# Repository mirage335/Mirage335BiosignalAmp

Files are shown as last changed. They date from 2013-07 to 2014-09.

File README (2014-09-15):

Copyright (C) 2012 mirage335
See the end of the file for license conditions.
See license.txt for Mirage335BiosignalAmp license conditions.

mirage335-site.dyndns.org
mirage335.dyndns.org/wiki/Mirage335BiosignalAmp
wiki.hacdc.org/index.php/Category:BiosignalAmplifier

Intended to represent the best achievable biosignal amplifier with commercially available components and dry electrodes. Input referred thermal noise across a 50Hz bandwidth should be about one microvolt at worst. Common-mode rejection is subject to real world conditions, but should far exceed commercial units.

New research was undertaken to select the best amplifier chips. See http://mirage335.dyndns.org/forums/viewtopic.php?f=4&t=16&sid=d09e2b47990c60269356eae3b596c3e3 for details.

USA companies provide all parts in these schematics.

__Usage__
The Driven Right Leg may be connected to any reference point on the body. The connection need not be very solid; it is far less critical than the active electrodes. Despite the name, for EEG purposes, the right leg may introduce undesirable ECG signals from the heart. An armband or heavy necklace may be more convenient.

The active electrodes may be used with pin headers in firm contact with dry skin, or saline sponges. Active electrode PCBs should be thoroughly and carefully sealed with hot glue or other heavy sealant.

Host board may be connected to USB, for signal processing with the Biosignal Processor software (https://github.com/mirage335/BiosignalProcessor), or taken directly in analog format from the BNC connector.

__Setup__
Obtain all parts from MOUSER/DigiKey as specified in the HTML Bill-Of-Materials files. Obtain circuit boards from oshpark.

Assemble the boards by placing and soldering components as per the PCB and BOM files. Recommend reflow soldering with laser cut solder stencil, except for the front-end high-performance amplifier chips.

PCB pads are provided for connection to metal shields. Aluminum foil, metal tins, and even random insullated wire may be effective.

Both power supplies should be > +/-6V < +/-15V . Mouser part 919-RS-1212D may provide suitable power.

SATA data cables are used to carry analog signals and power in one shielded cable.

Host board analog signal and USB outputs may be safely connected to non-isolated equipment, subject to the lightning strike warning below.

Host board USB data acqusition system is derrived from ArduinoDAQ. Essentially an Arduino Leonardo clone, an ISP programmer or arduino is required to flash firmware.

__Safety__
TEST the "HV Suppressor" transistor circuits. They protect users from amplifier chips failing short-circuit to power supply rails.

The safety critical isolation line marked on the test board includes upstream components. These must not be exposed to >25uA ground referenced current. Batteries may be safe when properly connected. Wall-warts, ATX power supplies, and even electrical grounds, are extremely dangerous.

Nearby lightning strikes will penetrate the isolation amplifier. A low-impedance earth connection to -ONLY- the non-isolated Vgnd may divert these faults. Alternatively, some 3-prong surge protectors may help, but they must clamp fast and well below 1.5kV. 
High frequency radio transmissions will penetrate the isolation amplifier. Amateur radio operators should be careful.

Passive electrodes -must- include the HV suppressors found on the active electrode boards. The most convenient way to build passive electrodes is to replace the amplifier chip on the active electrode board with a wire between pins 3 and 6.

No claim of liability is made by anyone. Your accident is your accident. Use common sense. If you don't understand the safety features and limitations, don't use this circuit.

__Copyright__
This file is part of Mirage335BiosignalAmp.

Mirage335BiosignalAmp is free software: you can redistribute it and/or modify
it under the terms of the GNU General Public License as published by
the Free Software Foundation, either version 3 of the License, or
(at your option) any later version.

Mirage335BiosignalAmp is distributed in the hope that it will be useful,
but WITHOUT ANY WARRANTY; without even the implied warranty of
MERCHANTABILITY or FITNESS FOR A PARTICULAR PURPOSE.  See the
GNU General Public License for more details.

You should have received a copy of the GNU General Public License
along with Mirage335BiosignalAmp.  If not, see <http://www.gnu.org/licenses/>.

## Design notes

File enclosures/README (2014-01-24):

These enclosures are still under development, having been partially tested on older versions of the Mirage335BiosignalAmplifier hardware. They may require significant readjustment.

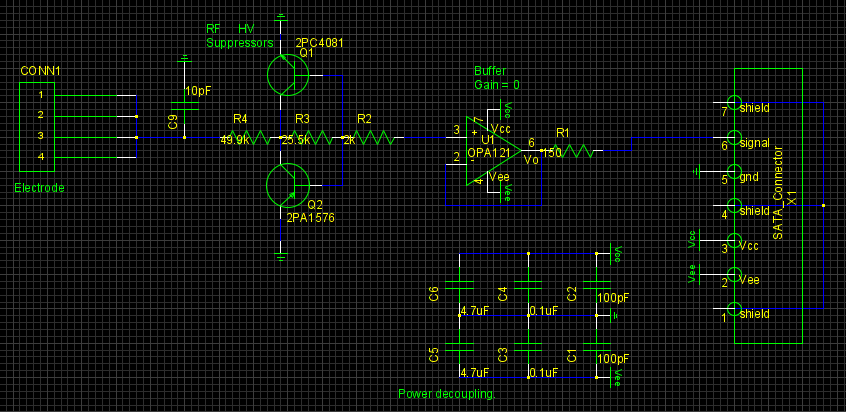
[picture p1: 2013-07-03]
activeElectrodeSchematic.png

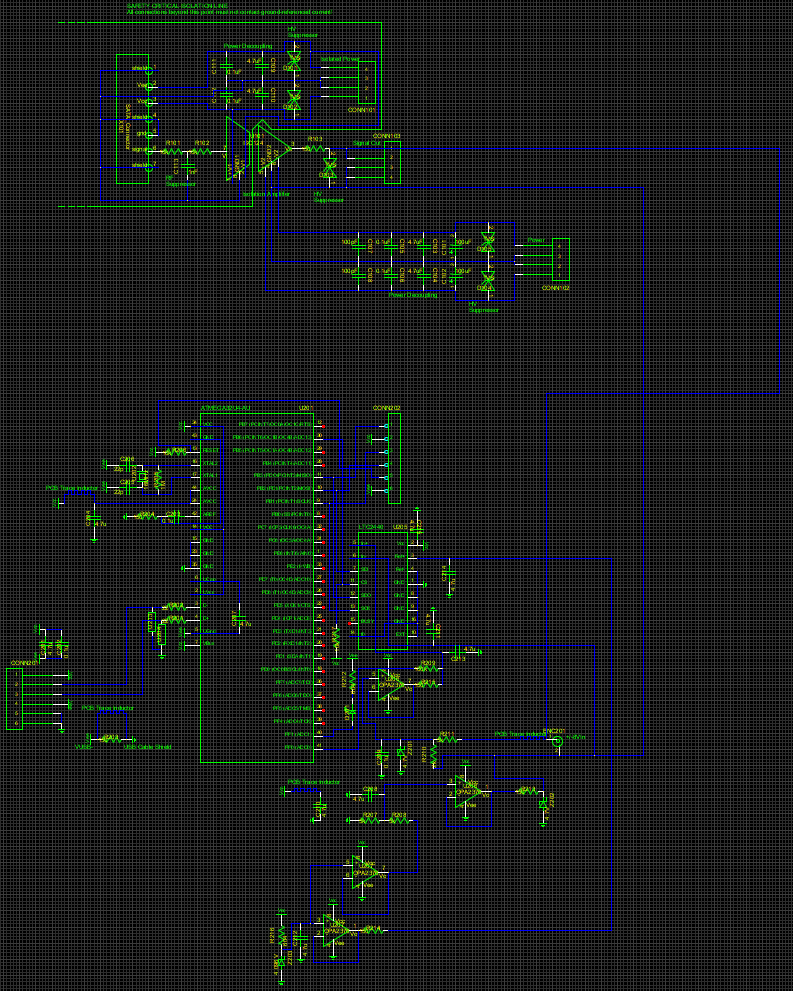
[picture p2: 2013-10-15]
hostSchematic.png

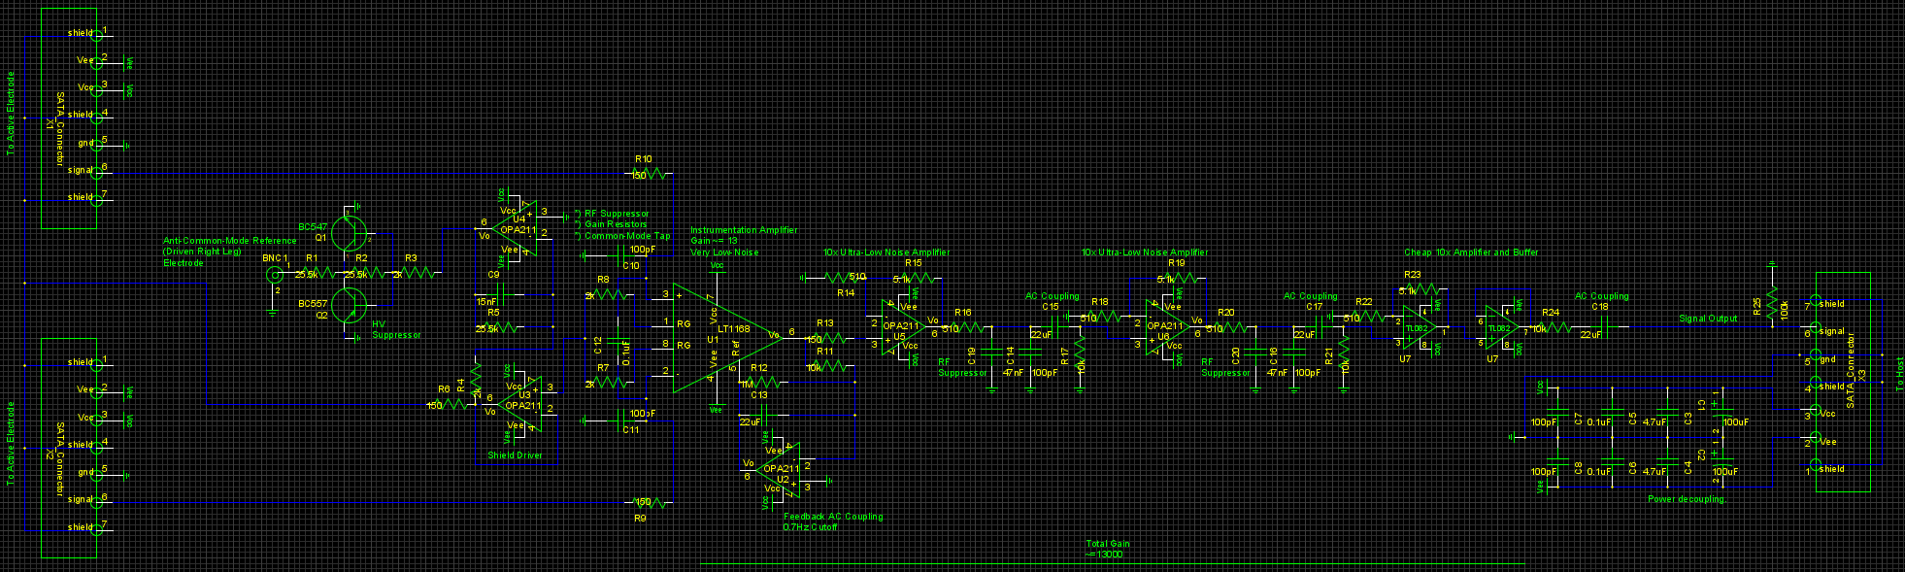
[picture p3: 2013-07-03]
amplifierSchematic.png

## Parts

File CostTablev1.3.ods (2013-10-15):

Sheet: Parts
ActiveElectrode
U1 | OPA121 | OPA121 | - | SO8 | $12.06 | 1 | $12.06 | 2 | $24.12
R4 | RESISTOR | RESISTOR | 49.9k | 1206 | $0.55 | 1 | $0.55 | 2 | $1.10
C5,C6 | CAPACITOR | CAPACITOR | 4.7uF | 1206 | $0.45 | 2 | $0.90 | 2 | $1.80
C3,C4 | CAPACITOR | CAPACITOR | 0.1uF | 1206 | $0.10 | 2 | $0.20 | 2 | $0.40
C1,C2 | CAPACITOR | CAPACITOR | 100pF | 805 | $1.04 | 2 | $2.08 | 2 | $4.16
R2 | RESISTOR | RESISTOR | 2k | 1206 | $0.55 | 1 | $0.55 | 2 | $1.10
R3 | RESISTOR | RESISTOR | 25.5k | 1206 | $0.55 | 1 | $0.55 | 2 | $1.10
C9 | CAPACITOR | CAPACITOR | 10pF | 805 | $0.62 | 1 | $0.62 | 2 | $1.24
R1 | RESISTOR | RESISTOR | 150 | 1206 | $0.55 | 1 | $0.55 | 2 | $1.10
X1 | SATA_Connector | SATA_Connector | - | 517-5607-4200-SH | $0.81 | 1 | $0.81 | 2 | $1.62
CONN1 | CONNECTOR_4 | OTHER | - | HEADER4_1 | $0.15 | 1 | $0.15 | 2 | $0.30
Q2 | 2PA1576 | OTHER | - | SC70_3 | $0.05 | 1 | $0.05 | 2 | $0.10
Q1 | 2PC4081 | OTHER | - | SC70_3 | $0.05 | 1 | $0.05 | 2 | $0.10
Amplifier |  | OTHER
U1 | LT1168 | LT1168 | - | SO8 | $7.66 | 1 | $7.66 | 1 | $7.66
R12 | RESISTOR | RESISTOR | 1M | 1206 | $0.09 | 1 | $0.09 | 1 | $0.09
R10,R13,R6,R9 | RESISTOR | RESISTOR | 150 | 1206 | $0.55 | 4 | $2.20 | 1 | $2.20
C9 | CAPACITOR | CAPACITOR | 15nF | 1206 | $0.27 | 1 | $0.27 | 1 | $0.27
U2,U3,U4,U5,U6 | OPA211 | OPA211 | - | SO8 | $7.76 | 5 | $38.80 | 1 | $38.80
U7 | TL082 | OTHER | - | SO8 | $0.45 | 1 | $0.45 | 1 | $0.45
C10,C11,C16 | CAPACITOR | CAPACITOR | 100pF | 805 | $1.04 | 3 | $3.12 | 1 | $3.12
C15,C17 | CAPACITOR | CAPACITOR | 22uF | 1210 | $1.71 | 2 | $3.42 | 1 | $3.42 | $3.42
R14,R16,R18,R20,R22 | RESISTOR | RESISTOR | 510 | 1206 | $0.09 | 5 | $0.45 | 1 | $0.45
R15,R19,R23 | RESISTOR | RESISTOR | 5.1k | 1206 | $0.10 | 3 | $0.30 | 1 | $0.30
R11,R17,R21,R24 | RESISTOR | RESISTOR | 10k | 1206 | $0.09 | 4 | $0.36 | 1 | $0.36
R3,R4,R7,R8 | RESISTOR | RESISTOR | 2k | 1206 | $0.55 | 4 | $2.20 | 1 | $2.20
C1,C2 | POLARIZED_CAPACITOR | POLARIZED_CAPACITOR | 100uF | EIA7343 | $2.96 | 2 | $5.92 | 1 | $5.92 | $5.92
C3,C4 | CAPACITOR | CAPACITOR | 4.7uF | 1206 | $0.45 | 2 | $0.90 | 1 | $0.90
C14,C7,C8 | CAPACITOR | CAPACITOR | 100pF | 805 | $1.04 | 3 | $3.12 | 1 | $3.12 | $3.12
R1,R2,R5 | RESISTOR | RESISTOR | 25.5k | 1206 | $0.55 | 3 | $1.65 | 1 | $1.65
Q1 | BC547 | OTHER | - | TO92 | $0.06 | 1 | $0.06 | 1 | $0.06
BNC1 | BNC | OTHER | - | BNC_LAY | $1.74 | 1 | $1.74 | 1 | $1.74
C12,C5,C6 | CAPACITOR | CAPACITOR | 0.1uF | 1206 | $0.10 | 3 | $0.30 | 1 | $0.30
X1,X2,X3 | SATA_Connector | SATA_Connector | - | 517-5607-4200-SH | $0.81 | 3 | $2.43 | 1 | $2.43
C19,C20 | CAPACITOR | CAPACITOR | 47nF | 1206 | $0.18 | 2 | $0.36 | 1 | $0.36
R25 | RESISTOR | RESISTOR | 100k | 805 | $0.16 | 1 | $0.16 | 1 | $0.16
C13,C18 | CAPACITOR | CAPACITOR | 22uF | 1210 | $1.71 | 2 | $3.42 | 1 | $3.42
Q2 | PNP_TRANSISTOR | OTHER | BC557 | TO92 | $0.07 | 1 | $0.07 | 1 | $0.07
Host |  | OTHER
X101 | SATA_Connector | SATA_Connector | - | 517-5607-4200-SH | $0.81 | 1 | $0.81 | 1 | $0.81
U101 | ISO124 | ISO124 | - | DIP16_highIsolation | $16.42 | 1 | $16.42 | 1 | $16.42
C101,C102 | POLARIZED_CAPACITOR | POLARIZED_CAPACITOR | 100uF | EIA7343 | $2.96 | 2 | $5.92 | 1 | $5.92
C107,C108 | CAPACITOR | CAPACITOR | 100pF | 805 | $1.04 | 2 | $2.08 | 1 | $2.08
C105,C106,C111,C112 | CAPACITOR | CAPACITOR | 0.1uF | 1206 | $0.10 | 4 | $0.40 | 1 | $0.40
C113 | CAPACITOR | CAPACITOR | 1nF | 1206 | $0.07 | 1 | $0.07 | 1 | $0.07
D101,D102,D103,D104,D105 | TVS | OTHER | - | DO214AB | $0.33 | 5 | $1.65 | 1 | $1.65
CONN101,CONN102,CONN103 | CONNECTOR_4 | OTHER | - | HEADER4_1 | $0.37 | 3 | $1.11 | 1 | $1.11
C103,C104,C109,C110 | CAPACITOR | CAPACITOR | 4.7uF | 1206 | $0.45 | 4 | $1.80 | 1 | $1.80
U201 | ATMEGA32U4-AU | ATMEGA32U4-AU | - | TQFP44_10 | $6.04 | 1 | $6.04 | 1 | $6.04
R205 | RESISTOR | RESISTOR | 1M | 1206 | $0.09 | 1 | $0.09 | 1 | $0.09
U202 | CRYSTAL | OTHER | 16MHz | ACY200 | $0.39 | 1 | $0.39 | 1 | $0.39
C205,C206 | CAPACITOR | CAPACITOR | 22p | 805 | $0.10 | 2 | $0.20 | 1 | $0.20
CONN202 | CONNECTOR_6 | OTHER | - | HEADER6_2 | $0.25 | 1 | $0.25 | 1 | $0.25
R201,R202 | RESISTOR | RESISTOR | 22 | 805 | $0.52 | 2 | $1.04 | 1 | $1.04
U203,U204 | ESD_Suppressor | OTHER | - | 603 | $0.13 | 2 | $0.26 | 1 | $0.26
CONN201 | CONNECTOR_6 | OTHER | - | USB_B | $0.58 | 1 | $0.58 | 1 | $0.58
R209 | RESISTOR | RESISTOR | 100k | 805 | $0.16 | 1 | $0.16 | 1 | $0.16
C202,C203,C209 | CAPACITOR | CAPACITOR | 0.1u | 1206 | $0.10 | 3 | $0.30 | 1 | $0.30
U205 | LTC2440 | LTC2440 | - | SSOP16 | $11.18 | 1 | $11.18 | 1 | $11.18
D201 | LED | OTHER | - | 402 | $0.09 | 1 | $0.09 | 1 | $0.09
R210 | RESISTOR | RESISTOR | 2k | 1206 | $0.55 | 1 | $0.55 | 1 | $0.55
R207,R208,R211 | RESISTOR | RESISTOR | 5k | 805 | $0.16 | 3 | $0.48 | 1 | $0.48
BNC201 | BNC | OTHER | - | BNC_LAY | $1.74 | 1 | $1.74 | 1 | $1.74
Z203 | ZENER_DIODE | OTHER | 4.096 V | SOT23 | $0.66 | 1 | $0.66 | 1 | $0.66
R212,R216 | RESISTOR | RESISTOR | 604 | 1206 | $0.85 | 2 | $1.70 | 1 | $1.70
U206,U207 | OPA2376 | OTHER | - | SO8 | $2.47 | 2 | $4.94 | 1 | $4.94
R103,R203,R204,R213,R214,R215 | RESISTOR | RESISTOR | 150 | 1206 | $0.55 | 6 | $3.30 | 1 | $3.30
Z201,Z202 | ZENER_DIODE | OTHER | 4.7V | ALF400 | $0.10 | 2 | $0.20 | 1 | $0.20
C201,C204,C207,C208,C210,C211,C212,C213,C214,C215 | CAPACITOR | CAPACITOR | 4.7u | 1206 | $0.45 | 10 | $4.50 | 1 | $4.50
R101,R102,R206,R217 | RESISTOR | RESISTOR | 10k | 1206 | $0.09 | 4 | $0.36 | 1 | $0.36
 |  |  |  |  |  |  |  |  | $186.96
 |  |  |  |  |  |  |  |  | TOTAL

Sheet: PCBs
Oshpark Small Run
ActiveElectrode | Amplifier | Host | Total
$5.70 | $81.30 | $47.10 | $134.10

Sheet: Report
DIY Totals |  |  |  | Minimum Mass Production Cost
Parts | PCBs | Grand |  | $219.20
$186.96 | $134.10 | $321.06
Components
OPA121 | LT1168 | OPA211 | ISO124 | LTC2440 | ATMEGA32U4-AU | RESISTOR | CAPACITOR | POLARIZED_CAPACITOR | SATA_Connector | OTHER
$24.12 | $7.66 | $38.80 | $16.42 | $11.18 | $6.04 | $19.49 | $31.86 | $11.84 | $4.86 | $14.69
Part Types
Chips | Passives | Other
$104.22 | $63.19 | $19.55

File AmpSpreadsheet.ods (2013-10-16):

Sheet: Stats
Name | Type | Corp | Price | Vs | CMRR | nV/√(Hz) | pA/√(Hz) | Vn@Ω@bw | Vn@Ω@f
INA114 | Instrumentation | BB/TI | $10.80 | 36 | 115 | 15 | 0.4 | 7.02E-07 | 9.93E-08
INA111 | Instrumentation | BB/TI | $10.80 | 36 | 106 | 40 | 0.1 | 5.12E-07 | 7.24E-08
INA103 | Instrumentation | BB/TI | $11.25 | 50 | 100 | 11 | 200 | 2.83E-04 | 4.00E-05
INA116 | Instrumentation | BB/TI | $9.45 | 36 | 84 | 110 | 0.01 | 8.76E-07 | 1.24E-07
INA110 | Instrumentation | BB/TI | $13.85 | 36 | 106 | 40 | 0.2 | 5.67E-07 | 8.02E-08
AD620 | Instrumentation | Analog | $8.03 | 36 | 80 | 11 | 3 | 4.26E-06 | 6.03E-07
AD624 | Instrumentation | Analog | $29.45 | 36 | 80 | 20 | 19 | 2.69E-05 | 3.80E-06
AD623 | Instrumentation | Analog | $3.86 | 12 | 90 | 60 | 0.47 | 8.85E-07 | 1.25E-07
LT1167 | Instrumentation | LT | $6.41 | 40 | 90 | 12 | 0.124 | 4.47E-07 | 6.32E-08
LT1168 | Instrumentation | LT | $7.66 | 40 | 90 | 12 | 0.074 | 4.24E-07 | 6.00E-08
LT1920 | Instrumentation | LT | $6.28 | 40 | 75 | 12 | 0.124 | 4.47E-07 | 6.32E-08
LME49990 | Operational | TI/NS | $3.22 | 36 | 0 | 2 | 28 | 3.96E-05 | 5.60E-06
OPA211 | Operational | TI | $3.88 | 36 | 0 | 2 | 3.2 | 4.54E-06 | 6.43E-07
LMP7721 | Operational | TI | $10.57 | 6 | 0 | 50 | 1 | 1.51E-06 | 2.14E-07
LMV791 | Operational | TI/NS | $1.55 | 6 | 0 | 12 | 1 | 1.47E-06 | 2.08E-07
OPA376 | Operational | TI | $1.46 | 7 | 0 | 12 | 0.2 | 4.99E-07 | 7.06E-08
OPA121 | Operational | TI/BB | $12.06 | 36 | 0 | 40 | 0.002 | 4.92E-07 | 6.95E-08
OPA376 | Operational | TI | $1.46 | 7 | 0 | 11 | 0.2 | 4.98E-07 | 7.04E-08
LMC6001 | Operational | TI/NS | $12.30 | 16 | 0 | 95 | 0.13 | 8.04E-07 | 1.14E-07
LTC6240 | Operational | LT | $1.76 | 7 | 0 | 15 | 0.001 | 4.16E-07 | 5.88E-08
LT1124 | Operational | LT | $7.04 | 44 | 0 | 6 | 4 | 5.67E-06 | 8.02E-07
LT1128 | Operational | LT | $9.55 | 44 | 0 | 1.9 | 12 | 1.70E-05 | 2.40E-06
MAX4475 | Operational | Maxim | $1.79 | 6 | 0 | 23 | 0.05 | 4.40E-07 | 6.22E-08
MAX9632 | Operational | Maxim | $9.12 | 40 | 0 | 2 | 375 | 5.30E-04 | 7.50E-05
AD743 | Operational | Analog | $10.34 | 36 | 0 | 4 | 0.03 | 4.05E-07 | 5.73E-08

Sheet: Tolerance
nV/√(Hz) | pA/√(Hz) | Vn@Ω@bw | NoiseMax | nV/√(Hz) | pA/√(Hz) | Vn@Ω@bw | NoiseMax
0 | 0 | 4.02E-07 | 1.00E-06 | 0 | 0 | 4.02E-07 | 1.00E-06
1.5 | 0 | 4.02E-07 | 1.00E-06 | 0 | 0.01 | 4.02E-07 | 1.00E-06
3 | 0 | 4.03E-07 | 1.00E-06 | 0 | 0.02 | 4.03E-07 | 1.00E-06
4.5 | 0 | 4.03E-07 | 1.00E-06 | 0 | 0.03 | 4.04E-07 | 1.00E-06
6 | 0 | 4.04E-07 | 1.00E-06 | 0 | 0.04 | 4.06E-07 | 1.00E-06
7.5 | 0 | 4.06E-07 | 1.00E-06 | 0 | 0.05 | 4.08E-07 | 1.00E-06
9 | 0 | 4.07E-07 | 1.00E-06 | 0 | 0.06 | 4.11E-07 | 1.00E-06
10.5 | 0 | 4.09E-07 | 1.00E-06 | 0 | 0.07 | 4.14E-07 | 1.00E-06
12 | 0 | 4.11E-07 | 1.00E-06 | 0 | 0.08 | 4.18E-07 | 1.00E-06
13.5 | 0 | 4.13E-07 | 1.00E-06 | 0 | 0.09 | 4.22E-07 | 1.00E-06
15 | 0 | 4.16E-07 | 1.00E-06 | 0 | 0.1 | 4.26E-07 | 1.00E-06
16.5 | 0 | 4.19E-07 | 1.00E-06 | 0 | 0.11 | 4.31E-07 | 1.00E-06
18 | 0 | 4.22E-07 | 1.00E-06 | 0 | 0.12 | 4.37E-07 | 1.00E-06
19.5 | 0 | 4.25E-07 | 1.00E-06 | 0 | 0.13 | 4.42E-07 | 1.00E-06
21 | 0 | 4.29E-07 | 1.00E-06 | 0 | 0.14 | 4.48E-07 | 1.00E-06
22.5 | 0 | 4.32E-07 | 1.00E-06 | 0 | 0.15 | 4.55E-07 | 1.00E-06
24 | 0 | 4.37E-07 | 1.00E-06 | 0 | 0.16 | 4.61E-07 | 1.00E-06
25.5 | 0 | 4.41E-07 | 1.00E-06 | 0 | 0.17 | 4.69E-07 | 1.00E-06
27 | 0 | 4.45E-07 | 1.00E-06 | 0 | 0.18 | 4.76E-07 | 1.00E-06
28.5 | 0 | 4.50E-07 | 1.00E-06 | 0 | 0.19 | 4.84E-07 | 1.00E-06
30 | 0 | 4.55E-07 | 1.00E-06 | 0 | 0.2 | 4.92E-07 | 1.00E-06
31.5 | 0 | 4.60E-07 | 1.00E-06 | 0 | 0.21 | 5.00E-07 | 1.00E-06
33 | 0 | 4.65E-07 | 1.00E-06 | 0 | 0.22 | 5.08E-07 | 1.00E-06
34.5 | 0 | 4.70E-07 | 1.00E-06 | 0 | 0.23 | 5.17E-07 | 1.00E-06
36 | 0 | 4.76E-07 | 1.00E-06 | 0 | 0.24 | 5.26E-07 | 1.00E-06
37.5 | 0 | 4.82E-07 | 1.00E-06 | 0 | 0.25 | 5.35E-07 | 1.00E-06
39 | 0 | 4.88E-07 | 1.00E-06 | 0 | 0.26 | 5.45E-07 | 1.00E-06
40.5 | 0 | 4.94E-07 | 1.00E-06 | 0 | 0.27 | 5.55E-07 | 1.00E-06
42 | 0 | 5.00E-07 | 1.00E-06 | 0 | 0.28 | 5.64E-07 | 1.00E-06
43.5 | 0 | 5.06E-07 | 1.00E-06 | 0 | 0.29 | 5.74E-07 | 1.00E-06
45 | 0 | 5.13E-07 | 1.00E-06 | 0 | 0.3 | 5.85E-07 | 1.00E-06
46.5 | 0 | 5.19E-07 | 1.00E-06 | 0 | 0.31 | 5.95E-07 | 1.00E-06
48 | 0 | 5.26E-07 | 1.00E-06 | 0 | 0.32 | 6.05E-07 | 1.00E-06
49.5 | 0 | 5.33E-07 | 1.00E-06 | 0 | 0.33 | 6.16E-07 | 1.00E-06
51 | 0 | 5.40E-07 | 1.00E-06 | 0 | 0.34 | 6.27E-07 | 1.00E-06
52.5 | 0 | 5.47E-07 | 1.00E-06 | 0 | 0.35 | 6.38E-07 | 1.00E-06
54 | 0 | 5.55E-07 | 1.00E-06 | 0 | 0.36 | 6.49E-07 | 1.00E-06
55.5 | 0 | 5.62E-07 | 1.00E-06 | 0 | 0.37 | 6.60E-07 | 1.00E-06
57 | 0 | 5.69E-07 | 1.00E-06 | 0 | 0.38 | 6.71E-07 | 1.00E-06
58.5 | 0 | 5.77E-07 | 1.00E-06 | 0 | 0.39 | 6.83E-07 | 1.00E-06
60 | 0 | 5.85E-07 | 1.00E-06 | 0 | 0.4 | 6.94E-07 | 1.00E-06
61.5 | 0 | 5.92E-07 | 1.00E-06 | 0 | 0.41 | 7.06E-07 | 1.00E-06
63 | 0 | 6.00E-07 | 1.00E-06 | 0 | 0.42 | 7.17E-07 | 1.00E-06
64.5 | 0 | 6.08E-07 | 1.00E-06 | 0 | 0.43 | 7.29E-07 | 1.00E-06
66 | 0 | 6.16E-07 | 1.00E-06 | 0 | 0.44 | 7.41E-07 | 1.00E-06
67.5 | 0 | 6.24E-07 | 1.00E-06 | 0 | 0.45 | 7.53E-07 | 1.00E-06
69 | 0 | 6.32E-07 | 1.00E-06 | 0 | 0.46 | 7.65E-07 | 1.00E-06
70.5 | 0 | 6.41E-07 | 1.00E-06 | 0 | 0.47 | 7.77E-07 | 1.00E-06
72 | 0 | 6.49E-07 | 1.00E-06 | 0 | 0.48 | 7.89E-07 | 1.00E-06
73.5 | 0 | 6.57E-07 | 1.00E-06 | 0 | 0.49 | 8.01E-07 | 1.00E-06
75 | 0 | 6.66E-07 | 1.00E-06 | 0 | 0.5 | 8.13E-07 | 1.00E-06
76.5 | 0 | 6.74E-07 | 1.00E-06 | 0 | 0.51 | 8.26E-07 | 1.00E-06
78 | 0 | 6.83E-07 | 1.00E-06 | 0 | 0.52 | 8.38E-07 | 1.00E-06
79.5 | 0 | 6.91E-07 | 1.00E-06 | 0 | 0.53 | 8.51E-07 | 1.00E-06
81 | 0 | 7.00E-07 | 1.00E-06 | 0 | 0.54 | 8.63E-07 | 1.00E-06
82.5 | 0 | 7.09E-07 | 1.00E-06 | 0 | 0.55 | 8.76E-07 | 1.00E-06
84 | 0 | 7.17E-07 | 1.00E-06 | 0 | 0.56 | 8.88E-07 | 1.00E-06
85.5 | 0 | 7.26E-07 | 1.00E-06 | 0 | 0.57 | 9.01E-07 | 1.00E-06
87 | 0 | 7.35E-07 | 1.00E-06 | 0 | 0.58 | 9.14E-07 | 1.00E-06
88.5 | 0 | 7.44E-07 | 1.00E-06 | 0 | 0.59 | 9.26E-07 | 1.00E-06
90 | 0 | 7.53E-07 | 1.00E-06 | 0 | 0.6 | 9.39E-07 | 1.00E-06
91.5 | 0 | 7.62E-07 | 1.00E-06 | 0 | 0.61 | 9.52E-07 | 1.00E-06
93 | 0 | 7.71E-07 | 1.00E-06 | 0 | 0.62 | 9.65E-07 | 1.00E-06
94.5 | 0 | 7.80E-07 | 1.00E-06 | 0 | 0.63 | 9.78E-07 | 1.00E-06
96 | 0 | 7.89E-07 | 1.00E-06 | 0 | 0.64 | 9.90E-07 | 1.00E-06
97.5 | 0 | 7.98E-07 | 1.00E-06 | 0 | 0.65 | 1.00E-06 | 1.00E-06
99 | 0 | 8.07E-07 | 1.00E-06 | 0 | 0.66 | 1.02E-06 | 1.00E-06
100.5 | 0 | 8.17E-07 | 1.00E-06 | 0 | 0.67 | 1.03E-06 | 1.00E-06
102 | 0 | 8.26E-07 | 1.00E-06 | 0 | 0.68 | 1.04E-06 | 1.00E-06
103.5 | 0 | 8.35E-07 | 1.00E-06 | 0 | 0.69 | 1.06E-06 | 1.00E-06
105 | 0 | 8.44E-07 | 1.00E-06 | 0 | 0.7 | 1.07E-06 | 1.00E-06
106.5 | 0 | 8.54E-07 | 1.00E-06 | 0 | 0.71 | 1.08E-06 | 1.00E-06
108 | 0 | 8.63E-07 | 1.00E-06 | 0 | 0.72 | 1.09E-06 | 1.00E-06
109.5 | 0 | 8.72E-07 | 1.00E-06 | 0 | 0.73 | 1.11E-06 | 1.00E-06
111 | 0 | 8.82E-07 | 1.00E-06 | 0 | 0.74 | 1.12E-06 | 1.00E-06
112.5 | 0 | 8.91E-07 | 1.00E-06 | 0 | 0.75 | 1.13E-06 | 1.00E-06
114 | 0 | 9.01E-07 | 1.00E-06 | 0 | 0.76 | 1.15E-06 | 1.00E-06
115.5 | 0 | 9.10E-07 | 1.00E-06 | 0 | 0.77 | 1.16E-06 | 1.00E-06
117 | 0 | 9.20E-07 | 1.00E-06 | 0 | 0.78 | 1.17E-06 | 1.00E-06
118.5 | 0 | 9.29E-07 | 1.00E-06 | 0 | 0.79 | 1.19E-06 | 1.00E-06
120 | 0 | 9.39E-07 | 1.00E-06 | 0 | 0.8 | 1.20E-06 | 1.00E-06
121.5 | 0 | 9.49E-07 | 1.00E-06 | 0 | 0.81 | 1.21E-06 | 1.00E-06
123 | 0 | 9.58E-07 | 1.00E-06 | 0 | 0.82 | 1.23E-06 | 1.00E-06
124.5 | 0 | 9.68E-07 | 1.00E-06 | 0 | 0.83 | 1.24E-06 | 1.00E-06
126 | 0 | 9.78E-07 | 1.00E-06 | 0 | 0.84 | 1.25E-06 | 1.00E-06
127.5 | 0 | 9.87E-07 | 1.00E-06 | 0 | 0.85 | 1.27E-06 | 1.00E-06
129 | 0 | 9.97E-07 | 1.00E-06 | 0 | 0.86 | 1.28E-06 | 1.00E-06
130.5 | 0 | 1.01E-06 | 1.00E-06 | 0 | 0.87 | 1.29E-06 | 1.00E-06
132 | 0 | 1.02E-06 | 1.00E-06 | 0 | 0.88 | 1.31E-06 | 1.00E-06
133.5 | 0 | 1.03E-06 | 1.00E-06 | 0 | 0.89 | 1.32E-06 | 1.00E-06
135 | 0 | 1.04E-06 | 1.00E-06 | 0 | 0.9 | 1.33E-06 | 1.00E-06
136.5 | 0 | 1.05E-06 | 1.00E-06 | 0 | 0.91 | 1.35E-06 | 1.00E-06
138 | 0 | 1.06E-06 | 1.00E-06 | 0 | 0.92 | 1.36E-06 | 1.00E-06
139.5 | 0 | 1.07E-06 | 1.00E-06 | 0 | 0.93 | 1.38E-06 | 1.00E-06
141 | 0 | 1.08E-06 | 1.00E-06 | 0 | 0.94 | 1.39E-06 | 1.00E-06
142.5 | 0 | 1.08E-06 | 1.00E-06 | 0 | 0.95 | 1.40E-06 | 1.00E-06
144 | 0 | 1.09E-06 | 1.00E-06 | 0 | 0.96 | 1.42E-06 | 1.00E-06
145.5 | 0 | 1.10E-06 | 1.00E-06 | 0 | 0.97 | 1.43E-06 | 1.00E-06
147 | 0 | 1.11E-06 | 1.00E-06 | 0 | 0.98 | 1.44E-06 | 1.00E-06
148.5 | 0 | 1.12E-06 | 1.00E-06 | 0 | 0.99 | 1.46E-06 | 1.00E-06
150 | 0 | 1.13E-06 | 1.00E-06 | 0 | 1 | 1.47E-06 | 1.00E-06

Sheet: App
NoiseMax | Input Impedance |  |  | Temp | Bandwidth | Gain | MinFreq
µV | Total | + | - | degC | Hz | 10 | 10
1 | 200000 | 1.0E+05 | 1.0E+05 | 293 | 50

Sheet: License
The MIT License (MIT) Copyright (c) 2012 mirage335 Permission is hereby granted, free of charge, to any person obtaining a copy of this software and associated documentation files (the "Software"), to deal in the Software without restriction, including without limitation the rights to use, copy, modify, merge, publish, distribute, sublicense, and/or sell copies of the Software, and to permit persons to whom the Software is furnished to do so, subject to the following conditions: The above copyright notice and this permission notice shall be included in all copies or substantial portions of the Software. THE SOFTWARE IS PROVIDED "AS IS", WITHOUT WARRANTY OF ANY KIND, EXPRESS OR IMPLIED, INCLUDING BUT NOT LIMITED TO THE WARRANTIES OF MERCHANTABILITY, FITNESS FOR A PARTICULAR PURPOSE AND NONINFRINGEMENT. IN NO EVENT SHALL THE AUTHORS OR COPYRIGHT HOLDERS BE LIABLE FOR ANY CLAIM, DAMAGES OR OTHER LIABILITY, WHETHER IN AN ACTION OF CONTRACT, TORT OR OTHERWISE, ARISING FROM, OUT OF OR IN CONNECTION WITH THE SOFTWARE OR THE USE OR OTHER DEALINGS IN THE SOFTWARE.

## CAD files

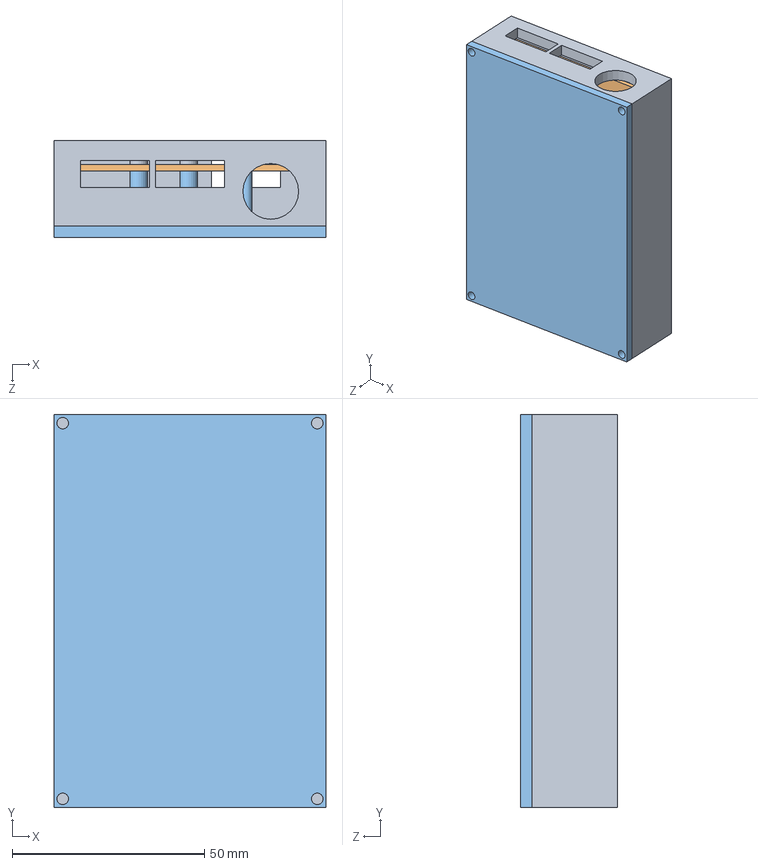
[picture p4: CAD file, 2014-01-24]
enclosures/Amplifier/Assem1.SLDASM
70.7 x 102.2 x 25.2 mm
PCB_Pad
PCB
FacePlate

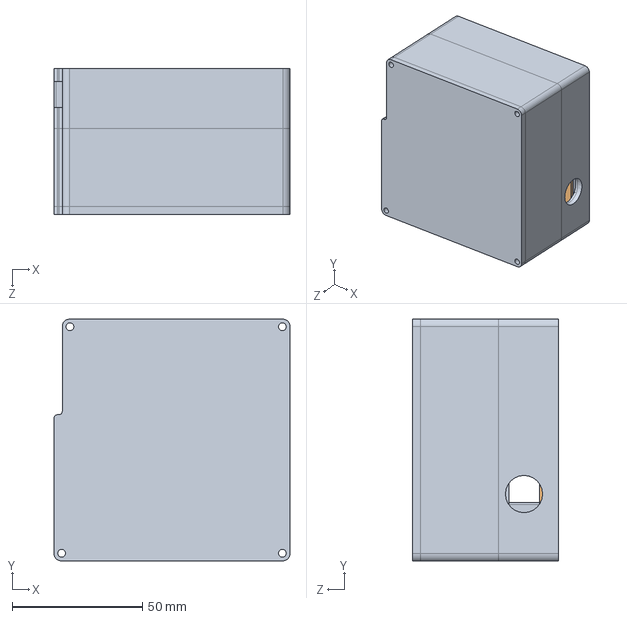
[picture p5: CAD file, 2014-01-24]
enclosures/Host/Assem1.SLDASM
90.4 x 92.6 x 56.0 mm
PCB_Pad x 3
PCB

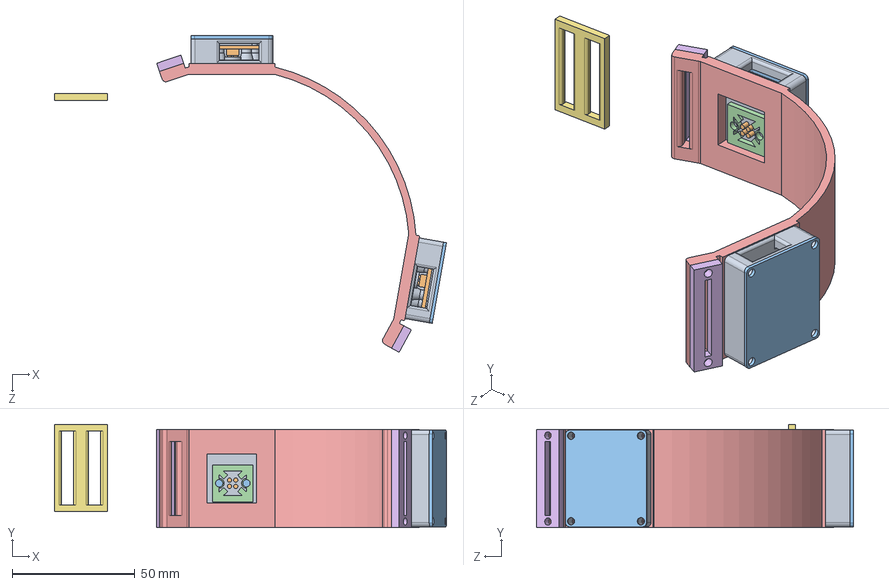
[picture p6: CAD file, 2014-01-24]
enclosures/Headset/ActiveElectrodeHeadset.SLDASM
159.4 x 42.0 x 128.7 mm
FacePlate x 2
PCB x 2
PCB_Pad x 2
SpongeAttachment x 2
Bracket
ElasticClamp x 2
ElasticBracket

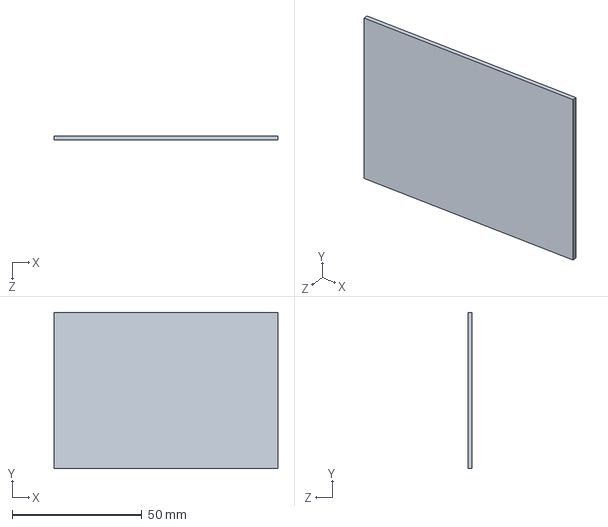
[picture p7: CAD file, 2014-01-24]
enclosures/Amplifier/PCB.SLDPRT
86.4 x 60.3 x 1.65 mm

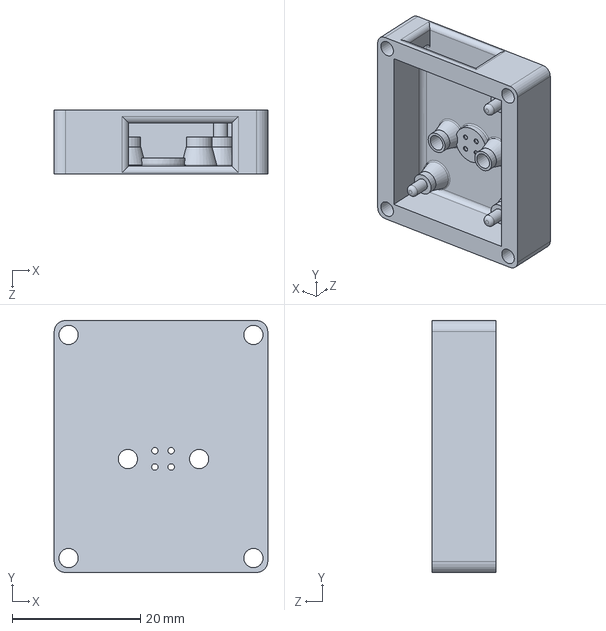
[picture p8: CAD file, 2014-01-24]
enclosures/Headset/FacePlate.SLDPRT
33.3 x 39.3 x 10.0 mm

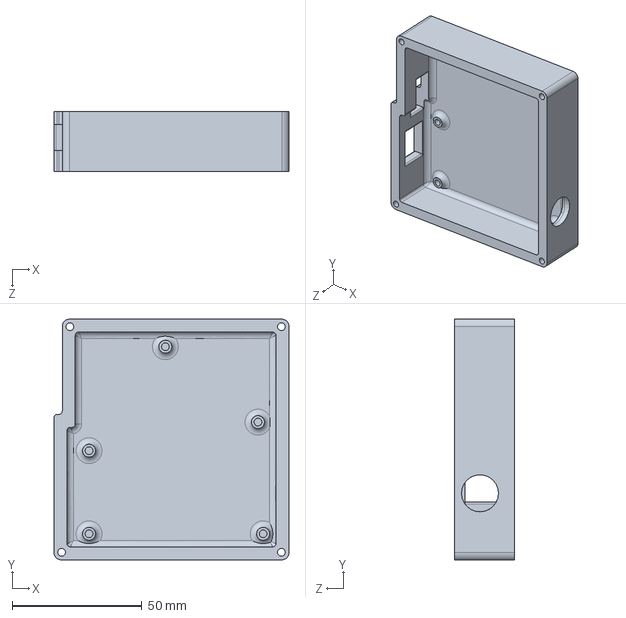
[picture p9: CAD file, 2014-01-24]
enclosures/Host/PCB_Pad.SLDPRT
90.4 x 92.6 x 23.0 mm

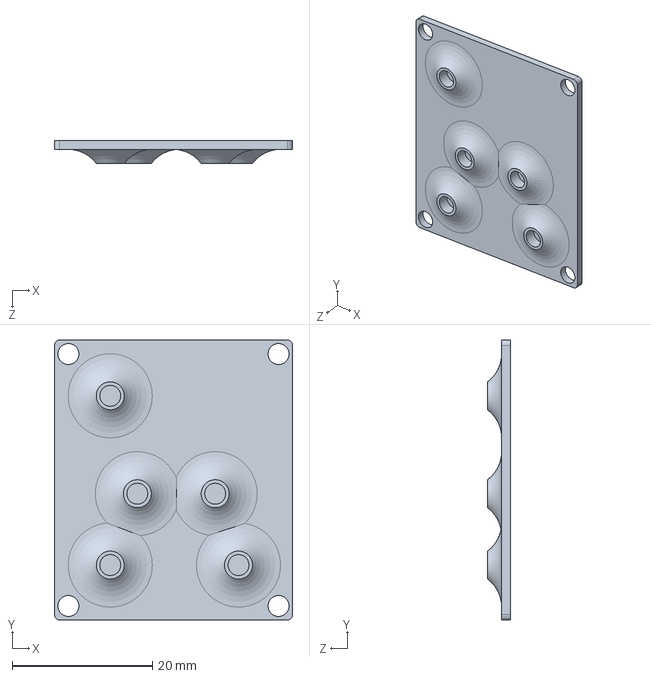
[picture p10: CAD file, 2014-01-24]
enclosures/Headset/PCB_Pad.SLDPRT
34.0 x 39.9 x 3.25 mm

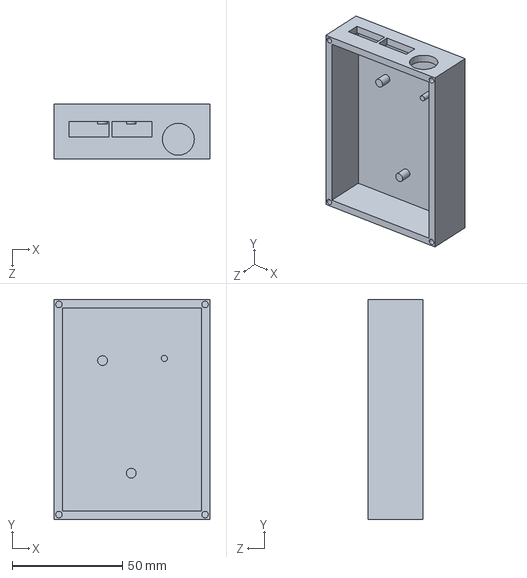
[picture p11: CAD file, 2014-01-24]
enclosures/Amplifier/PCB_Pad.SLDPRT
70.7 x 99.7 x 25.0 mm

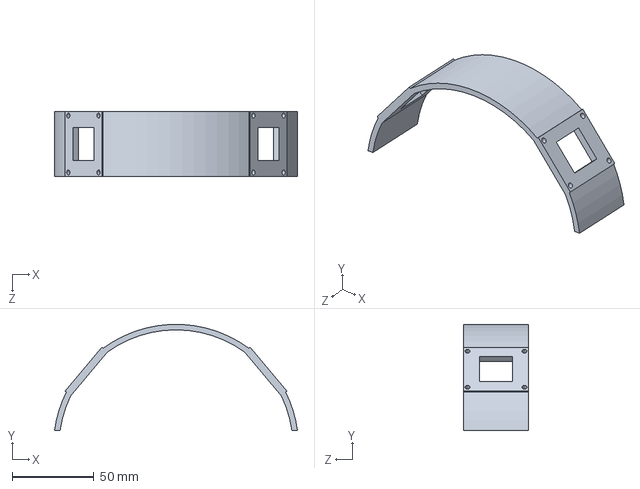
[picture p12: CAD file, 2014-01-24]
enclosures/Headset/Bracket.SLDPRT
148.7 x 64.9 x 40.0 mm

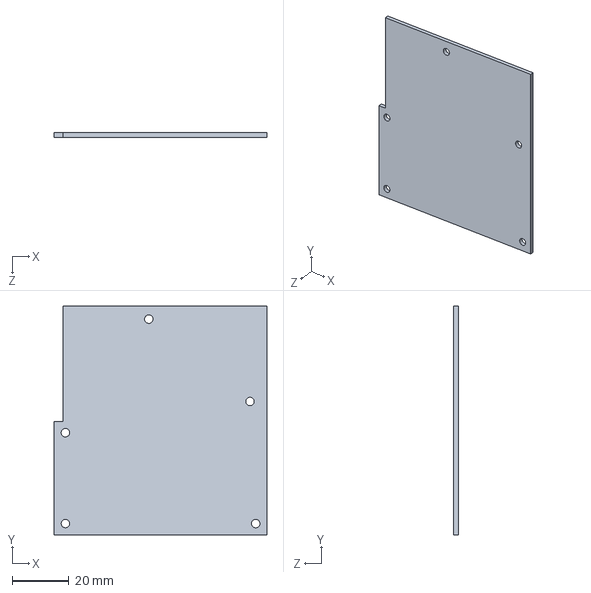
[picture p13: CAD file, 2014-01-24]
enclosures/Host/PCB.SLDPRT
74.9 x 80.6 x 1.60 mm

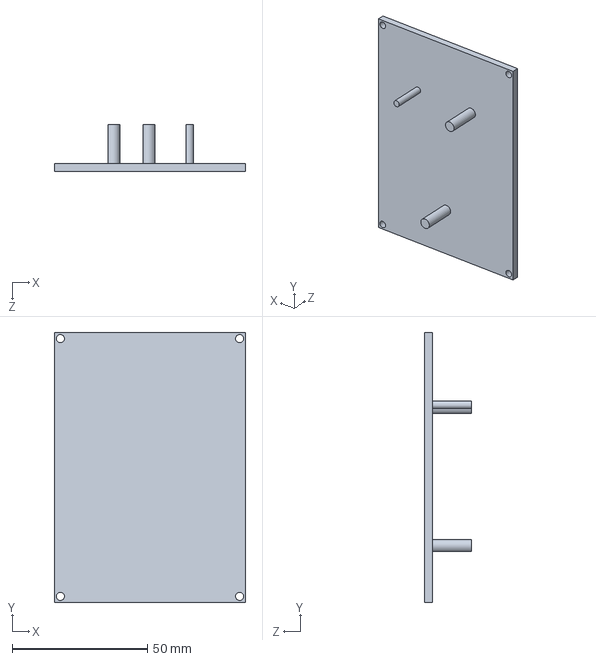
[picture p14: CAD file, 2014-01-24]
enclosures/Amplifier/FacePlate.SLDPRT
70.7 x 99.7 x 17.4 mm

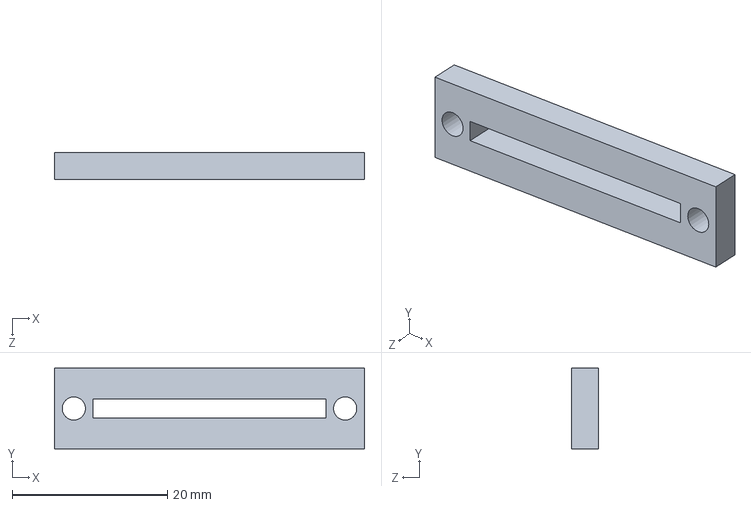
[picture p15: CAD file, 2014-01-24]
enclosures/Headset/ElasticClamp.SLDPRT
40.0 x 10.4 x 3.50 mm

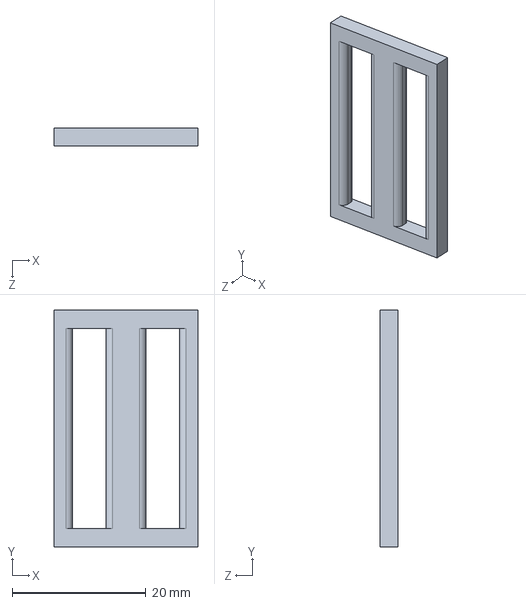
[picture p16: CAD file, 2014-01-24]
enclosures/Headset/ElasticBracket.SLDPRT
21.5 x 35.5 x 2.75 mm

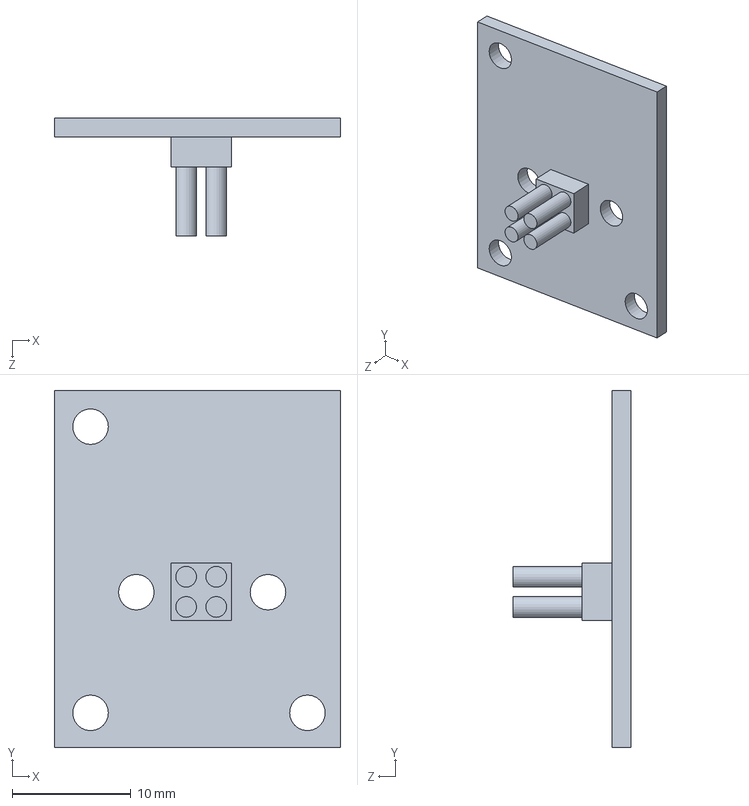
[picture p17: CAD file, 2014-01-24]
enclosures/Headset/PCB.SLDPRT
24.1 x 30.1 x 9.98 mm

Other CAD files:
enclosures/Headset/SpongeAttachment.SLDPRT

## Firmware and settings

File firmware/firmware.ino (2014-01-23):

/*
The MIT License (MIT)

Copyright (c) 2013 mirage335

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
THE SOFTWARE IS PROVIDED "AS IS", WITHOUT WARRANTY OF ANY KIND, EXPRESS OR
IMPLIED, INCLUDING BUT NOT LIMITED TO THE WARRANTIES OF MERCHANTABILITY,
FITNESS FOR A PARTICULAR PURPOSE AND NONINFRINGEMENT. IN NO EVENT SHALL THE
AUTHORS OR COPYRIGHT HOLDERS BE LIABLE FOR ANY CLAIM, DAMAGES OR OTHER
LIABILITY, WHETHER IN AN ACTION OF CONTRACT, TORT OR OTHERWISE, ARISING FROM,
OUT OF OR IN CONNECTION WITH THE SOFTWARE OR THE USE OR OTHER DEALINGS IN
THE SOFTWARE.
*/

/*
http://mirage335-site.dyndns.org
*/

/*
Credits:
Original example, "Interface between Arduino DM board and Linear Tech LTC2440 24-bit ADC Nov. 12 2010 John Beale" by John Beale, found at http://dangerousprototypes.com/forum/viewtopic.php?f=2&t=4247 .
Interrupt code based on example at http://www.engblaze.com/microcontroller-tutorial-avr-and-arduino-timer-interrupts/ .
Binary union based on example at http://forum.arduino.cc/index.php?topic=112597.0 .
No licenses were found with these examples. Public domain or fair use assumed.
*/

/*
Arduino DAQ Firmware
Emits samples in S32_LE format over USB Serial (ie. /dev/tty?) at the rate specificied by the sampleRate variable. Up to 3000 samples/sec has been successfully tested.

Default 150Hz sample rate, low pass filtered down to 45Hz, suitable for EEG pickup.

Unix machines can process this data with the following commands, among others:
stty -F /dev/ttyACM0 raw ; echo -n "" > /dev/ttyACM0 ; timeout 10 cat /dev/ttyACM0 > test ; wc -c test
stty -F /dev/ttyACM0 raw ; echo -n "" > /dev/ttyACM0 ; cat /dev/ttyACM0 | aplay -f S32_LE
stty -F /dev/ttyACM0 raw ; echo -n "" > /dev/ttyACM0 ; hexdump /dev/ttyACM0
*/

//SPI and interrupt libraries.
#include <SPI.h>
#include <avr/io.h>
#include <avr/interrupt.h>

//#define debug

//Macro function for low pass filter.
//Overuse can cause data and precision loss, especially with non-float variables.
#define lowPass(newValue, filteredValue, inertiaFloat)                            \
  filteredValue = filteredValue + (inertiaFloat * (newValue - filteredValue));

//IIR Biquad Filter.
//Parameters b0, b1, b2, a1, a2 are filter coefficients. See http://gnuradio.4.n7.nabble.com/IIR-filter-td40994.html and http://www.earlevel.com/main/2013/10/13/biquad-calculator-v2/ .
//Data is returned in the float named [filteredValue] . This variable must be externally declared.
//State variables unique_d1_name and unique_d2_name should be statically declared floats.
#define IIRbiquad(newValue, filteredValue, unique_d1_name, unique_d2_name, b0, b1, b2, a1, a2)			\
														\
	filteredValue = b0 * newValue + unique_d1_name;								\
	unique_d1_name = (float)b1 * (float)newValue + (float)a1 * filteredValue + unique_d2_name; 	\
	unique_d2_name = (float)b2 * (float)newValue + (float)a2 * filteredValue;

//High Order IIR Biquad Filter.
//Parameters b0, b1, b2, a1, a2 are filter coefficients. See http://gnuradio.4.n7.nabble.com/IIR-filter-td40994.html and http://www.earlevel.com/main/2013/10/13/biquad-calculator-v2/ .
//Data is returned in the float named [filteredValue] .
#define highOrderIIRbiquad(newValue, filteredValue, stateOneArrayName, stateTwoArrayName, b0, b1, b2, a1, a2, filterOrder)	\
	static float stateOneArrayName[(filterOrder+1)];									\
	static float stateTwoArrayName[(filterOrder+1)];									\
	lowerOrderFilteredValue = newValue;											\
																\
	for (filterLoop=0; filterLoop < filterOrder; filterLoop++) {								\
		IIRbiquad(lowerOrderFilteredValue, filteredValue, stateOneArrayName[filterLoop], stateTwoArrayName[filterLoop], b0, b1, b2, a1, a2) \
		lowerOrderFilteredValue = filteredValue;									\
	}

typedef union {
  long longValue;
  byte binary[4];
} binaryLong;

typedef union {
  float floatValue;
  byte binary[4];
} binaryFloat;

//*****CONFIG*****

//Maximum sample rate is less than the LTC2440 conversion rate, defined by the oversampling ratio, set by the speedBits variable. Faster speedBits settings lead to increased noise and loss of built-in low-pass filter (anti-aliasing) characteristics. See Table 3 in the LTC2440 datasheet.
const int sampleRate = 150;                           //Desired sample rate in Hz. Test with stty -F /dev/ttyACM0 raw ; echo -n "" > /dev/ttyACM0 ; timeout 10 cat /dev/ttyACM0 > test ; wc -c test .
const int speedBits=0b0101;                           //Oversample ratio, determines LTC2440 bandwidth and maximum sampling rate. See datasheet Tabel 3. {0b0001 = 3.52kHz, 0b0010=1.76kHz, 0b0101=220Hz, 0b0110=110Hz, 0b1111=6.875Hz}

//Maximizes IIR low-pass anti-alias filtering.
//WARNING: Extremely high filter orders (>300) will consume too much RAM, and may break bootloaders.
//WARNING: Old code, for reference only.
//const int filterOrder = (2750/sampleRate*5)%300;    //Autocalculates IIR filter maximum order up to 300.
//const int filterOrder = 300;                      //Only use for sampling rates < 50Hz.

const byte slaveSelectPin = 10;  // digital pin 10 for /CS
const int led = A4;

//*****CONFIG*****

const int convertSpeed = 0b10000000 | speedBits<<3;

//Global vairables allow interrupt preemption.
float volts = 0;
#ifdef debug
int millisOffset;
unsigned long sampleCount = 0;
#endif

void setup() {
    Serial.begin(115200);  // Maybe a lot faster over native USB.
    
    //Initiates first conversion cycle.
    pinMode (slaveSelectPin, OUTPUT);
    digitalWrite(slaveSelectPin,LOW);   // chip select is active low
    digitalWrite(slaveSelectPin,HIGH);
    
    //Configure SPI.
    SPI.begin();                          // initialize SPI, covering MOSI,MISO,SCK signals
    SPI.setBitOrder(MSBFIRST);            // data is clocked in MSB first
    SPI.setDataMode(SPI_MODE0);           // SCLK idle low (CPOL=0), MOSI read on rising edge (CPHI=0)
    SPI.setClockDivider(SPI_CLOCK_DIV2);  //8MHz clock. 250000 32bit samples/sec may be read at this rate.
    
    //Startup LED indicator.
    pinMode (led, OUTPUT);
    
    for (int i=0; i<=10; i++) {
      delay(100);
      digitalWrite(led, HIGH);
      delay(100);
      digitalWrite(led, LOW);
    }
    
    //Configure interrupt handler. This provides preemption and an accurate sample rate.
    // initialize Timer1
    cli();          // disable global interrupts
    TCCR1A = 0;     // set entire TCCR1A register to 0
    TCCR1B = 0;     // same for TCCR1B
    // set compare match register to desired timer count:
    OCR1A = (int)(16000000/8/sampleRate); //Counter setup.
    TCCR1B |= (1 << WGM12);               // turn on CTC mode
    TCCR1B |= (1 << CS11);
    TIMSK1 |= (1 << OCIE1A);              // enable timer compare interrupt:
    sei();                                // enable global interrupts:
    
    #ifdef debug
    millisOffset = millis();
    #endif
}

//Non critical tasks. Preempted by interrrupt handler.
void loop()
{
  #ifdef debug
  //Catches some underruns. Disable in production, to prevent false-positive due to eventual overflow.
  if (sampleCount <  sampleRate * 0.99 * (millis() - millisOffset) / 1000) {
    digitalWrite(led, HIGH);
  }
  #endif
  
  //Clipping diagnostic LED.
  if (abs(volts) > 2.45)
    digitalWrite(led, HIGH);
  else
    digitalWrite(led, LOW);
  
  delay(150);
}

//Critical path. Sample, process, and transmit data.
ISR(TIMER1_COMPA_vect)
{
  //LTC2440 SPI data acqusition cycle.
  static long b3;
  static long b2;
  static long b1;
  static long b0;
  digitalWrite(slaveSelectPin,LOW);   // take the SS pin low to select the chip
  delayMicroseconds(1);              // probably not needed, only need 25 nsec delay
  b3 = SPI.transfer(convertSpeed);   // B3
  b2 = SPI.transfer(0x00);           // B2
  b1 = SPI.transfer(0x00);           // B1
  b0 = SPI.transfer(0x00);           // B0
  // take the SS pin high to de-select the chip:
  digitalWrite(slaveSelectPin,HIGH);  //Next conversion cycle begins here.
  static long in = 0;         // incoming serial 32-bit word
  in = b3<<8;
  in |= b2;
  in = in<<8;
  in |= b1;
  in = in<<8;
  in |= b0;
  in &= 0x1FFFFFFF; // force high three bits to zero
  in = in>>5;   // truncate lowest 5 bits
  
  //Conversion to accurate voltage.
  volts = (in * (0.2980232594) * 0.000001);
  if (volts > (2.5))
    volts=((5)-volts)*(-1);  //Polarity correction.
  
  //IIR filters augment LTC2440 built-in anti-alias filter and 60Hz rejection filter, particularly at lower oversample rates (higher conversion rates).
  static float filteredVolts=0;
  
  static int filterLoop;
  static float lowerOrderFilteredValue;
  
  //Low pass filter. 45Hz corner frequency at 150Hz sample rate.
  highOrderIIRbiquad(volts, filteredVolts, lowPassStateOne, lowPassStateTwo, 0.39133426347022965, 0.7826685269404593, 0.39133426347022965, -0.3695259524151477, -0.19581110146577096, 8);
  
  //High pass (AC coupling) filter. 0.35Hz corner frequency at 150Hz sample rate. Mostly useful for removing amplifier flicker noise.
  highOrderIIRbiquad(filteredVolts, filteredVolts, highPassStateOne, highPassStateTwo, 0.9896867236566386, -1.9793734473132771, 0.9896867236566386, 1.9792670828350616, -0.9794798117914928, 2);
  
  //60Hz notch filter at 150Hz sample rate.
  highOrderIIRbiquad(filteredVolts, filteredVolts, sixtyNotchStateOne, sixtyNotchStateTwo, 0.9883808858331896, 1.5992338671088302, 0.9883808858331896, -1.5992338671088302, -0.9767617716663792, 1);
  
  //30Hz notch filter at 150H sample rate.
  highOrderIIRbiquad(filteredVolts, filteredVolts, thirtyNotchStateOne, thirtyNotchStateTwo, 0.9813339196216473, -0.6064977166393354, 0.9813339196216473, 0.6064977166393354, -0.9626678392432946, 1);
  
  //Human readable format.
  //Serial.println("");
  //Serial.println((float)volts,6);             //Raw.
  //Serial.println((float)(filteredVolts),6);   //Filtered.
  
  //Prepare value for binary readout.
  static binaryLong convertableMicroVolts;
  convertableMicroVolts.longValue = filteredVolts * 1000000;
  
  //Optional gain. Drops dynamic range..
  //convertableMicroVolts.longValue *= (long)1000000;
  
  //convertableMicroVolts.longValue *= (long)10000;
  
  //Compatible with aplay -f S32_LE .
  Serial.write(convertableMicroVolts.binary,4);
  
  #ifdef debug
  sampleCount++;
  #endif
}

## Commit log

2012-11-15 Moved a few decoupling capacitors.
2013-03-18 Version 1.1
    [ActiveElectrode.sch, Amplifier.sch, Host.sch]
2013-03-27 Removes unused layers, assigns the GND layer to the bottom-side group
2013-03-27 Adds script to generate gerbers and minimally process for oshpark
2013-03-27 Remove unused layers from Host pcb to simplify gerber generation
2013-03-27 Removes unused layers in Amplifier board and updates gerber script for 4 layer parts
2013-03-27 Adds 1.1 gerbers
    [ActiveElectrode.bottom.gbr, ActiveElectrode.bottommask.gbr, ActiveElectrode.fab.gbr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]
2013-03-27 Adds oshpark compatible zip files for 1.1 boards
2013-03-28 Substatially improves/generalizes the generate-gerber script. Adds MIT License
2013-03-28 generate-gerbers.sh: Summarize each outputted board
2013-04-03 Ignore intermediate files generated by gsch2pcb in generate-gerbers.sh
2013-07-03 Version 1.2. Improved electrode PCBs, lower DRL cutoff frequency.
    [ActiveElectrode.sch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]
2013-10-15 USB support through merging of ArduinoDAQ project.
    [ActiveElectrode.bottom.gbr, ActiveElectrode.bottommask.gbr, ActiveElectrode.fab.gbr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]
2013-10-15 Version 1.3. USB DAQ system, merged from ArduinoDAQ.
    [ActiveElectrode.bottom.gbr, ActiveElectrode.bottommask.gbr, ActiveElectrode.fab.gbr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]
2013-10-15 Cost analysis spreadsheet.
    [CostTablev1.3.ods]
2013-10-15 Minor formatting improvement.
    [CostTablev1.3.ods]
2013-10-16 Chipamp comparison spreadsheet merged.
    [AmpSpreadsheet.ods]
2013-11-06 Improved ripple suppression.
    [Host.sch]
2013-11-06 Regenerated oshpark files.
    [ActiveElectrode.bottom.gbr, ActiveElectrode.bottommask.gbr, ActiveElectrode.fab.gbr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]
2014-01-23 New firmware with IIR biquad filters.
2014-01-24 Version 1.4. IIR biquad filters in firmware, SolidWorks files for 3D printable enclosures, updated documentation.
    [ActiveElectrodeHeadset.SLDASM, Assem1.SLDASM, Bracket.SLDPRT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]
2014-01-24 Current version updated.
